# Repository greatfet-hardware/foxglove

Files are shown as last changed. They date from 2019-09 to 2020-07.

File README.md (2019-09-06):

# Foxglove
an advanced level shifting GreatFET neighbor

Required KiCad dependency:

https://github.com/greatscottgadgets/gsg-kicad-lib

If you are using git, the preferred way to install gsg-kicad-lib is to use the
submodule:

```
git submodule init && git submodule update
```

## Level Shifting

Foxglove is useful for interfacing with external targets at variety of I/O
voltage levels using a wide variety of protocols including SPI, I2C, UART, and
JTAG.  Level shifting on bank A is performed by the NXP 74LVCH1T45GW,125
supporting external voltages from 1.2 V to 5 V.  Level shifting on bank B pins
is performed by the Lattice LFE5U-12F-6BG256C (ECP5) FPGA supporting external
voltages from 1.2 V to 3.3 V.  Bank B also supports differential signals such
as LVDS.

## Pin Multiplexing

The FPGA allows Foxglove to switch arbitrary external wires to a variety of
pins on the Azalea's microcontroller in order to support a wide range of
microcontroller peripherals.

## Measurement and Probing

Foxglove provides the ability to connect an ADC, DAC, comparator, pull-up
resistor, or pull-down resistor to any of the pins on bank A.  This allows
analog measurement and probing of external targets.

Additionally, Foxglove is very useful for digital logic analysis and pattern
generation.

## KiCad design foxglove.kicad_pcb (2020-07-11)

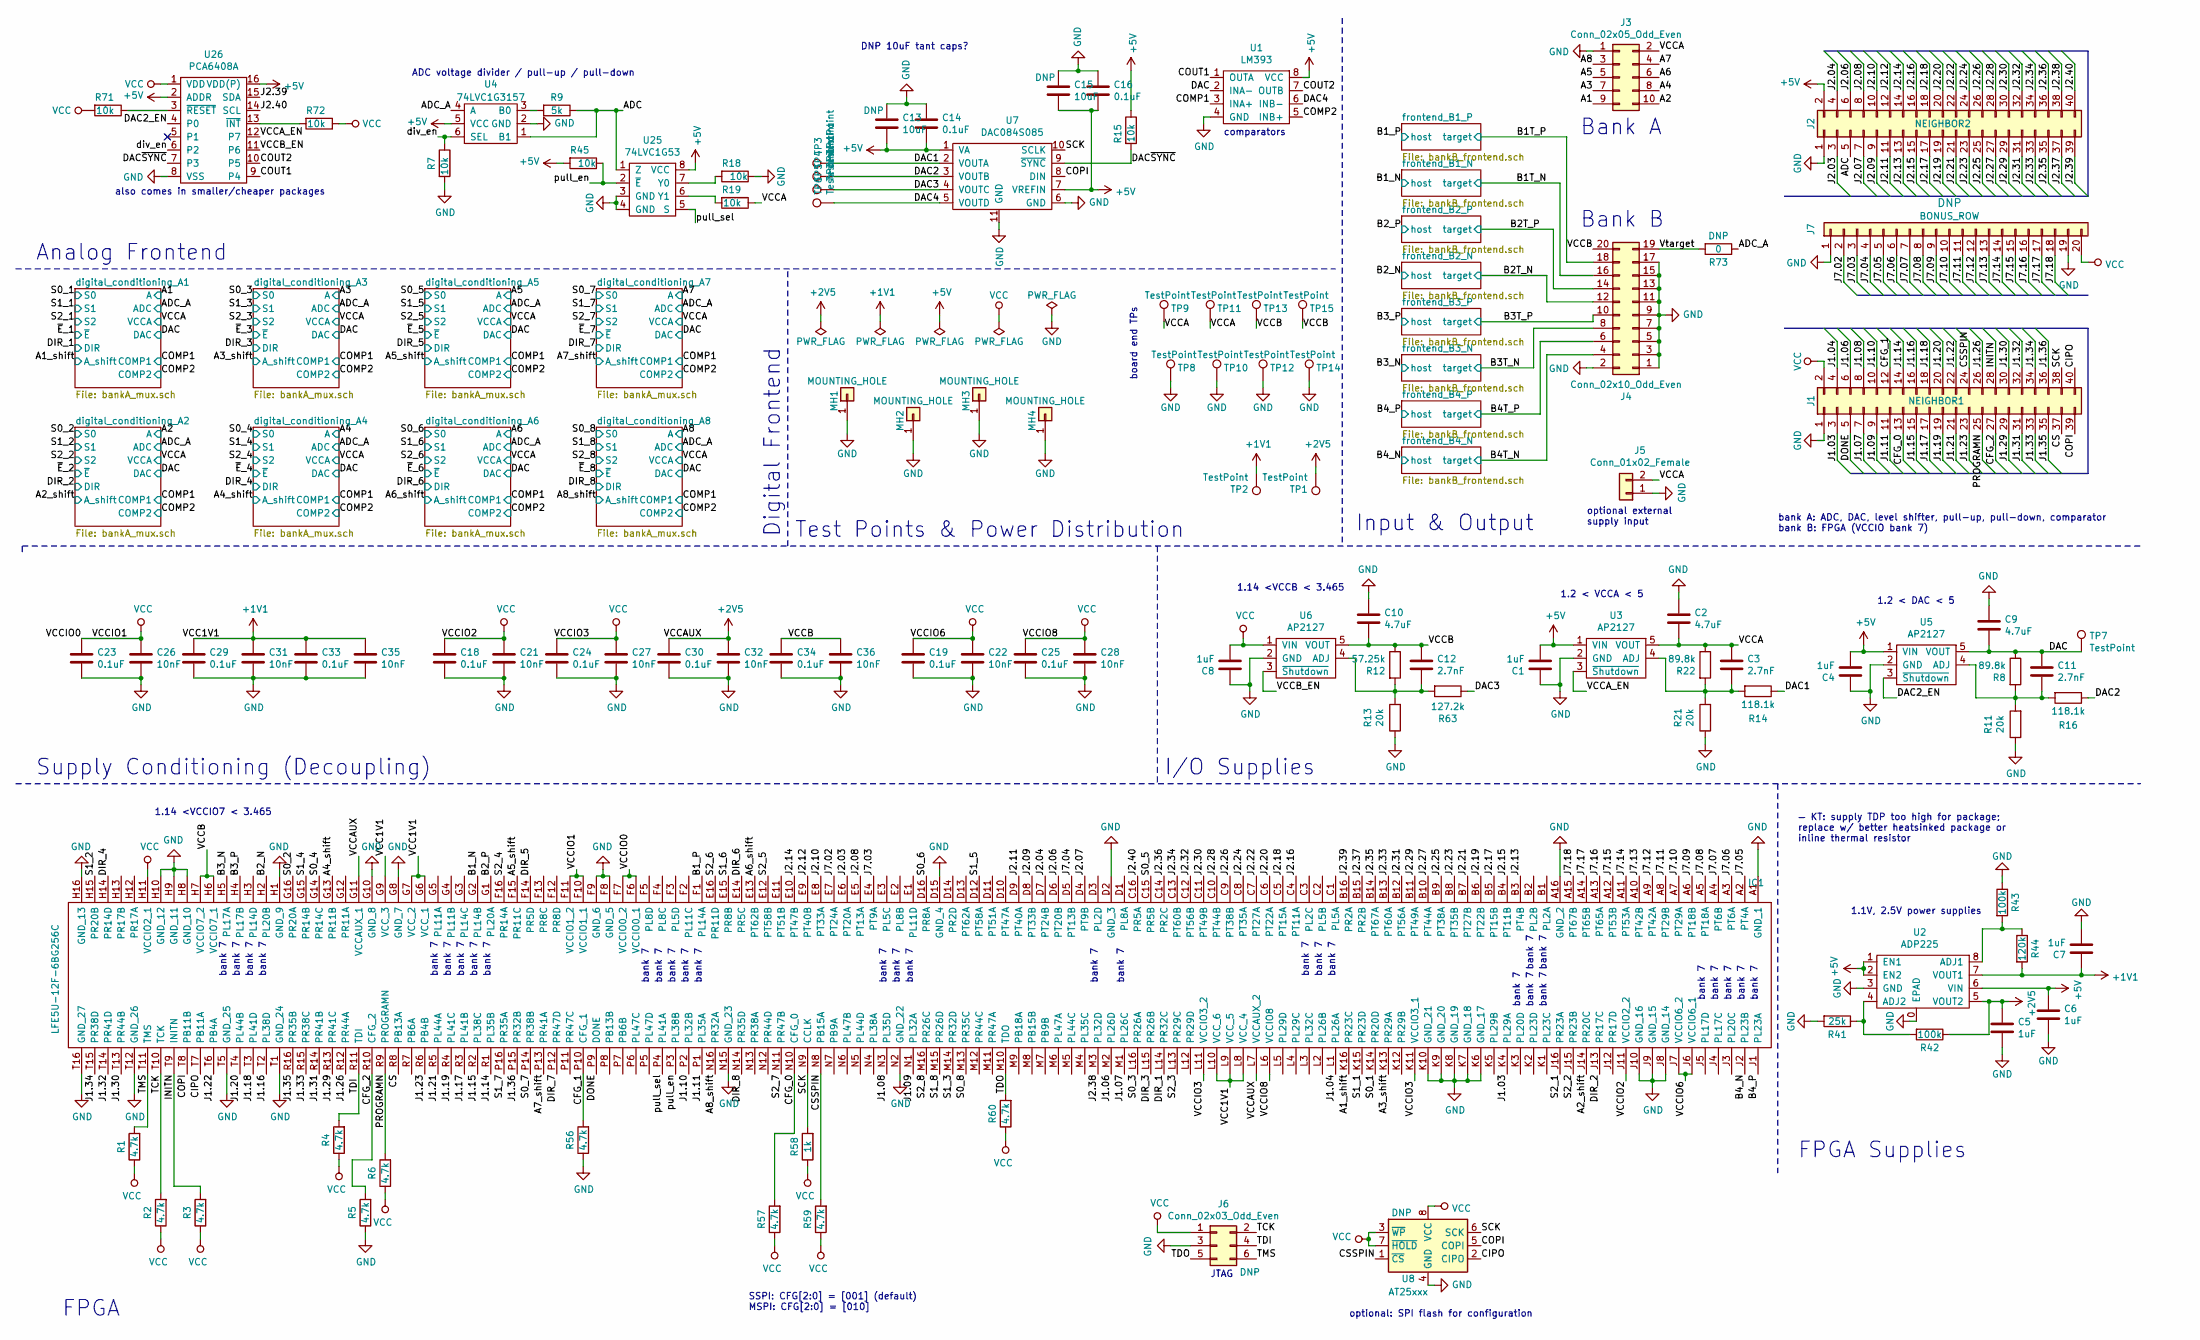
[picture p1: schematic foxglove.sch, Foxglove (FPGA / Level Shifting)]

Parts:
C1, C4, C5, C6, C7, C8: 1uF; 0402; Part Number GRT155R61E105KE01D
C2, C9, C10: 4.7uF; 0402; Part Number GRM155R61A475MEAAD
C3, C11, C12: 2.7nF; 0402; Part Number CC0402KRX7R9BB272
C13, C15: 10uF; 0603; Part Number F981A106MMA
C14, C16, C18, C19, C23, C24, C25, C29, C30, C33, C34: 0.1uF; 0402; Part Number EMK105BJ104KV-F
C21, C22, C26, C27, C28, C31, C32, C35, C36: 10nF; 0402; Part Number CL05B103KO5NNNC
IC1: LFE5U-12F-6BG256C; BGA256C80P16X16_1400X1400X170; Part Number LFE5U-12F-6BG256C; Mouser Part Number 842-LFE5U12F6BG256C
J1: NEIGHBOR1; HEADER-2x20; Part Number SSQ-120-23-G-D
J2: NEIGHBOR2; HEADER-2x20; Part Number SSQ-120-23-G-D
J3: Conn_02x05_Odd_Even; PinHeader_2x05_P2.54mm_Vertical; Part Number SBH11-PBPC-D05-RA-BK
J4: Conn_02x10_Odd_Even; PinHeader_2x10_P2.54mm_Vertical; Part Number SBH11-PBPC-D10-RA-BK
J5: Conn_01x02_Female; HEADER-1x2
J6: Conn_02x03_Odd_Even; PinHeader_2x03_P1.00mm_Vertical_SMD
J7: BONUS_ROW; HEADER-1x20; Part Number SSQ-120-23-G-S
MH1, MH2, MH3, MH4: MOUNTING_HOLE; HOLE126MIL-COPPER
R1, R2, R3, R4, R5, R6, R56, R57, R59, R60: 4.7k; 0402; Part Number RMCF0402JT4K70
R7, R15, R18, R19, R45, R71, R72: 10k; 0402; Part Number RMCF0402JT10K0
R8, R22: 89.8k; 0402; Part Number RMCF0402FT88K7
R9: 5k; 0402; Part Number PNM0402E5001BST1
R11, R13, R21: 20k; 0402; Part Number RMCF0402JT20K0
R12: 57.25k; 0402; Part Number RMCF0402FT57K6
R14, R16: 118.1k; 0402; Part Number RMCF0402FT118K
R41: 25k; 0402; Part Number PNM0402E2502BST1
R42, R43: 100k; 0402; Part Number RMCF0402JT100K
R44: 120k; 0402; Part Number RMCF0402FT120K
R58: 1k; 0402; Part Number RK73B1ETTP102J
R63: 127.2k; 0402; Part Number RMCF0402FT127K
R73: 0; 0402
TP1, TP2, TP3, TP4, TP5, TP6, TP7: TestPoint; TESTPOINT-50MIL
TP8, TP10, TP12, TP14: TestPoint; HEADER-1x1
TP9, TP11, TP13, TP15: TestPoint; HEADER-1x1-TESTPROBE
U1: LM393; SOIC8-154; Part Number LM393EDR2G
U2: ADP225; SON50P200X200X60-9N; Part Number ADP225ACPZ-R7
U3, U5, U6: AP2127; SOT-23-5; Part Number AP2127K-ADJTRG1
U4: 74LVC1G3157; SOT363; Part Number 74LVC1G3157DW-7
U7: DAC084S085; WSON-10-1EP_4x3mm_P0.5mm_EP2.2x2mm; Part Number DAC084S085CISDX/NOPB
U8: AT25xxx; SOIC8-154
U25: 74LVC1G53; VSSOP-8_2.3x2mm_P0.5mm; Part Number 74LVC1G53DC,125
U26: PCA6408A; TSSOP16; Part Number PCA6408APW,118

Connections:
+1V1: C7.1, C29.1, C31.1, C33.1, C35.1, IC1.G6 (VCC_1), IC1.G7 (VCC_2), IC1.G9 (VCC_3), IC1.L8 (VCC_4), IC1.L9 (VCC_5), IC1.L10 (VCC_6), R44.2, TP2.1, U2.7 (VOUT1)
+2V5: C5.1, C30.1, C32.1, IC1.G11 (VCCAUX_1), IC1.L7 (VCCAUX_2), R42.1, TP1.1, U2.5 (VOUT2)
+5V: C1.2, C4.2, C6.1, C13.1, C14.2, C15.1, C16.2, J2.2, R15.1, R45.2, U1.8 (VCC), U2.1 (EN1), U2.2 (EN2), U2.6 (VIN), U3.1 (VIN), U4.5 (VCC), U5.1 (VIN), U7.1 (VA), U7.7 (VREFIN), U25.8 (VCC), U26.2 (ADDR), U26.16 (VDD(P)); also elsewhere on the board
/A1_shift: IC1.K16 (PR23C); also elsewhere on the board
/A2: J3.10; also elsewhere on the board
/A2_shift: IC1.J14 (PR20C); also elsewhere on the board
/A3: J3.7; also elsewhere on the board
/A3_shift: IC1.K13 (PR29A); also elsewhere on the board
/A4_shift: IC1.G13 (PR11B); also elsewhere on the board
/A5: J3.5; also elsewhere on the board
/A5_shift: IC1.F15 (PR11C); also elsewhere on the board
/A6: J3.6; also elsewhere on the board
/A6_shift: IC1.E13 (PT62B); also elsewhere on the board
/A7: J3.4; also elsewhere on the board
/A7_shift: IC1.P13 (PR41A); also elsewhere on the board
/A8: J3.3; also elsewhere on the board
/A8_shift: IC1.N16 (PR32A); also elsewhere on the board
/ADC: J2.5, R9.1, U4.1 (B1), U25.1 (Z)
/ADC_A: R73.1, U4.4 (A); also elsewhere on the board
/B1T_N: J4.16; also elsewhere on the board
/B1T_P: J4.18; also elsewhere on the board
/B1_N: IC1.G2 (PL14B); also elsewhere on the board
/B1_P: IC1.F1 (PL14A); also elsewhere on the board
/B2T_N: J4.12; also elsewhere on the board
/B2T_P: J4.14; also elsewhere on the board
/B2_N: IC1.H2 (PL20B); also elsewhere on the board
/B2_P: IC1.G1 (PL20A); also elsewhere on the board
/B3T_N: J4.8; also elsewhere on the board
/B3T_P: J4.10; also elsewhere on the board
/B3_N: IC1.H5 (PL17A); also elsewhere on the board
/B3_P: IC1.H4 (PL17B); also elsewhere on the board
/B4T_N: J4.4; also elsewhere on the board
/B4T_P: J4.6; also elsewhere on the board
/B4_N: IC1.J2 (PL23B); also elsewhere on the board
/B4_P: IC1.J1 (PL23A); also elsewhere on the board
/CFG_0: IC1.N10 (CFG_0), J1.13, R57.2
/CFG_1: IC1.P10 (CFG_1), J1.12, R56.2
/CFG_2: IC1.R10 (CFG_2), J1.27, R5.2
/CIPO: IC1.T7 (PB11A), J1.40, U8.2 (CIPO)
/COMP1: U1.3 (INA+); also elsewhere on the board
/COMP2: U1.5 (INB+); also elsewhere on the board
/COPI: IC1.T8 (PB11B), J1.39, U7.8 (DIN), U8.5 (COPI)
/COUT1: U1.1 (OUTA), U26.9 (P4)
/COUT2: U1.7 (OUTB), U26.10 (P5)
/CS: IC1.R8 (PB13A), J1.37
/CSSPIN: IC1.N8 (PB15A), J1.24, R59.2, U8.1 (~CS)
/DAC: C9.2, C11.1, R8.1, TP7.1, U1.2 (INA-), U5.5 (VOUT); also elsewhere on the board
/DAC1: R14.1, TP3.1, U7.2 (VOUTA)
/DAC2: R16.1, TP4.1, U7.3 (VOUTB)
/DAC2_EN: U5.3 (~Shutdown~), U26.4 (P0)
/DAC3: R63.1, TP5.1, U7.4 (VOUTC)
/DAC4: TP6.1, U1.6 (INB-), U7.5 (VOUTD)
/DAC~SYNC~: R15.2, U7.9 (~SYNC~), U26.7 (P3)
/DIR_1: IC1.L14 (PR32C); also elsewhere on the board
/DIR_2: IC1.J13 (PR17C); also elsewhere on the board
/DIR_3: IC1.L15 (PR26B); also elsewhere on the board
/DIR_4: IC1.H14 (PR14D); also elsewhere on the board
/DIR_5: IC1.F14 (PR5D); also elsewhere on the board
/DIR_6: IC1.E14 (PR5C); also elsewhere on the board
/DIR_7: IC1.P12 (PR47D); also elsewhere on the board
/DIR_8: IC1.N14 (PR35D); also elsewhere on the board
/DONE: IC1.P9 (DONE), J1.5
/INITN: IC1.T9 (INITN), J1.28, R3.2
/J1.03: IC1.K4 (PL29A), J1.3
/J1.04: IC1.L1 (PL26A), J1.4
/J1.06: IC1.M2 (PL26D), J1.6
/J1.07: IC1.M1 (PL26C), J1.7
/J1.08: IC1.N3 (PL35D), J1.8
/J1.09: IC1.N1 (PL32A), J1.9
/J1.10: IC1.P2 (PL32B), J1.10
/J1.11: IC1.P1 (PL35A), J1.11
/J1.14: IC1.R1 (PL35B), J1.14
/J1.15: IC1.R2 (PL38C), J1.15
/J1.16: IC1.T2 (PL38D), J1.16
/J1.17: IC1.R3 (PL41B), J1.17
/J1.18: IC1.T3 (PL41D), J1.18
/J1.19: IC1.R4 (PL41C), J1.19
/J1.20: IC1.T4 (PL44B), J1.20
/J1.21: IC1.R5 (PL44A), J1.21
/J1.22: IC1.T6 (PB4A), J1.22
/J1.23: IC1.R6 (PB4B), J1.23
/J1.26: IC1.R12 (PR44A), J1.26
/J1.29: IC1.R13 (PR41C), J1.29
/J1.30: IC1.T13 (PR44B), J1.30
/J1.31: IC1.R14 (PR41B), J1.31
/J1.32: IC1.T14 (PR41D), J1.32
/J1.33: IC1.R15 (PR38C), J1.33
/J1.34: IC1.T15 (PR38D), J1.34
/J1.35: IC1.R16 (PR35B), J1.35
/J1.36: IC1.P15 (PR32B), J1.36
/J2.03: IC1.E6 (PT20A), J2.3
/J2.04: IC1.D7 (PT24B), J2.4
/J2.06: IC1.D6 (PT20B), J2.6
/J2.07: IC1.D4 (PT9B), J2.7
/J2.08: IC1.E5 (PT13A), J2.8
/J2.09: IC1.D8 (PT33B), J2.9
/J2.10: IC1.E8 (PT33A), J2.10
/J2.11: IC1.D9 (PT40A), J2.11
/J2.12: IC1.E9 (PT40B), J2.12
/J2.13: IC1.B3 (PT4B), J2.13
/J2.14: IC1.E10 (PT47B), J2.14
/J2.15: IC1.B4 (PT11B), J2.15
/J2.16: IC1.C4 (PT11A), J2.16
/J2.17: IC1.B5 (PT15B), J2.17
/J2.18: IC1.C5 (PT15A), J2.18
/J2.19: IC1.B6 (PT22B), J2.19
/J2.20: IC1.C6 (PT22A), J2.20
/J2.21: IC1.B7 (PT27B), J2.21
/J2.22: IC1.C7 (PT27A), J2.22
/J2.23: IC1.B8 (PT35B), J2.23
/J2.24: IC1.C8 (PT35A), J2.24
/J2.25: IC1.B9 (PT38A), J2.25
/J2.26: IC1.C9 (PT38B), J2.26
/J2.27: IC1.B10 (PT44A), J2.27
/J2.28: IC1.C10 (PT44B), J2.28
/J2.29: IC1.B11 (PT49A), J2.29
/J2.30: IC1.C11 (PT49B), J2.30
/J2.31: IC1.B12 (PT56A), J2.31
/J2.32: IC1.C12 (PT56B), J2.32
/J2.33: IC1.B13 (PT60A), J2.33
/J2.34: IC1.C13 (PT60B), J2.34
/J2.35: IC1.B14 (PT67A), J2.35
/J2.36: IC1.C14 (PR2C), J2.36
/J2.37: IC1.B15 (PR2B), J2.37
/J2.38: IC1.M3 (PL32D), J2.38
/J2.39: IC1.B16 (PR2A), J2.39, U26.15 (SDA)
/J2.40: IC1.C16 (PR5A), J2.40, U26.14 (SCL)
/J7.02: IC1.E7 (PT24A), J7.2
/J7.03: IC1.E4 (PT9A), J7.3
/J7.04: IC1.D5 (PT13B), J7.4
/J7.05: IC1.A2 (PT4A), J7.5
/J7.06: IC1.A3 (PT6A), J7.6
/J7.07: IC1.A4 (PT6B), J7.7
/J7.08: IC1.A5 (PT18A), J7.8
/J7.09: IC1.A6 (PT18B), J7.9
/J7.10: IC1.A7 (PT29A), J7.10
/J7.11: IC1.A8 (PT29B), J7.11
/J7.12: IC1.A9 (PT42A), J7.12
/J7.13: IC1.A10 (PT42B), J7.13
/J7.14: IC1.A11 (PT53A), J7.14
/J7.15: IC1.A12 (PT53B), J7.15
/J7.16: IC1.A13 (PT65A), J7.16
/J7.17: IC1.A14 (PT65B), J7.17
/J7.18: IC1.A15 (PT67B), J7.18
/PROGRAMN: IC1.R9 (PROGRAMN), J1.25, R6.2
/S0_1: IC1.K14 (PR20D); also elsewhere on the board
/S0_2: IC1.G16 (PR20A); also elsewhere on the board
/S0_3: IC1.L16 (PR26A); also elsewhere on the board
/S0_4: IC1.G14 (PR14C); also elsewhere on the board
/S0_5: IC1.C15 (PR5B); also elsewhere on the board
/S0_6: IC1.D16 (PR8A); also elsewhere on the board
/S0_7: IC1.P14 (PR38B); also elsewhere on the board
/S0_8: IC1.M13 (PR35C); also elsewhere on the board
/S1_1: IC1.K15 (PR23D); also elsewhere on the board
/S1_2: IC1.H15 (PR20B); also elsewhere on the board
/S1_3: IC1.M14 (PR32D); also elsewhere on the board
/S1_4: IC1.G15 (PR14B); also elsewhere on the board
/S1_5: IC1.D12 (PT58A); also elsewhere on the board
/S1_6: IC1.E15 (PR8B); also elsewhere on the board
/S1_7: IC1.P16 (PR35A); also elsewhere on the board
/S1_8: IC1.M15 (PR26D); also elsewhere on the board
/S2_1: IC1.J16 (PR23A); also elsewhere on the board
/S2_2: IC1.J15 (PR23B); also elsewhere on the board
/S2_3: IC1.L13 (PR29C); also elsewhere on the board
/S2_4: IC1.F16 (PR14A); also elsewhere on the board
/S2_5: IC1.E12 (PT58B); also elsewhere on the board
/S2_6: IC1.E16 (PR11D); also elsewhere on the board
/S2_7: IC1.N11 (PR47B); also elsewhere on the board
/S2_8: IC1.M16 (PR26C); also elsewhere on the board
/SCK: IC1.N9 (CCLK), J1.38, R58.2, U7.10 (SCLK), U8.6 (SCK)
/TCK: IC1.T10 (TCK), J6.2, R2.2
/TDI: IC1.R11 (TDI), J6.4, R4.2
/TDO: IC1.M10 (TDO), J6.5, R60.2
/TMS: IC1.T11 (TMS), J6.6, R1.2
/VCCA: C2.2, C3.1, J3.2, J5.2, R19.1, R22.1, TP9.1, TP11.1, U3.5 (VOUT); also elsewhere on the board
/VCCA_EN: U3.3 (~Shutdown~), U26.12 (P7)
/VCCB: C10.2, C12.1, C34.1, C36.1, IC1.H6 (VCCIO7_1), IC1.H7 (VCCIO7_2), J4.20, R12.1, TP13.1, TP15.1, U6.5 (VOUT)
/VCCB_EN: U6.3 (~Shutdown~), U26.11 (P6)
/Vtarget: J4.19, R73.2
/div_en: R7.1, U4.6 (SEL), U26.6 (P2)
/pull_en: IC1.P3 (PL38B), R45.1, U25.2 (~E~)
/pull_sel: IC1.P4 (PL41A), U25.5 (S)
GND: C1.1, C2.1, C4.1, C5.2, C6.2, C7.2, C8.1, C9.1, C10.1, C13.2, C14.1, C15.2, C16.1, C18.2, C19.2, C21.2, C22.2, C23.2, C24.2, C25.2, C26.2, C27.2, C28.2, C29.2, C30.2, C31.2, C32.2, C33.2, C34.2, C35.2, C36.2, IC1.A1 (GND_1), IC1.A16 (GND_2), IC1.D2 (GND_3), IC1.D15 (GND_4), IC1.F8 (GND_5), IC1.F9 (GND_6), IC1.G8 (GND_7), IC1.G10 (GND_8), IC1.H1 (GND_9), IC1.H8 (GND_10), IC1.H9 (GND_11), IC1.H10 (GND_12), IC1.H16 (GND_13), IC1.J8 (GND_14), IC1.J9 (GND_15), IC1.J10 (GND_16), IC1.K6 (GND_17), IC1.K7 (GND_18), IC1.K8 (GND_19), IC1.K9 (GND_20), IC1.K10 (GND_21), IC1.N2 (GND_22), IC1.N15 (GND_23), IC1.T1 (GND_24), IC1.T5 (GND_25), IC1.T12 (GND_26), IC1.T16 (GND_27), J1.1, J2.1, J3.1, J4.1, J4.2, J4.3, J4.5, J4.7, J4.9, J4.11, J4.13, J4.15, J4.17, J5.1, J6.3, J7.1, J7.19, MH1.1, MH2.1, MH3.1, MH4.1, R5.1, R7.2, R11.1, R13.1, R18.1, R21.1, R41.2, R43.1, R56.1, TP8.1, TP10.1, TP12.1, TP14.1, U1.4 (GND), U2.0 (EPAD), U2.3 (GND), U3.2 (GND), U4.2 (GND), U5.2 (GND), U6.2 (GND), U7.6 (GND), U7.11 (GND), U8.4 (GND), U25.3 (GND), U25.4 (GND), U26.8 (VSS); also elsewhere on the board
unnamed: C3.2, R14.2, R21.2, R22.2, U3.4 (ADJ)
unnamed: C11.2, R8.2, R11.2, R16.2, U5.4 (ADJ)
unnamed: C12.2, R12.2, R13.2, R63.2, U6.4 (ADJ)
unnamed: R9.2, U4.3 (B0)
unnamed: R18.2, U25.7 (Y0)
unnamed: R19.2, U25.6 (Y1)
unnamed: R41.1, R42.2, U2.4 (ADJ2)
unnamed: R43.2, R44.1, U2.8 (ADJ1)
unnamed: R71.1, U26.3 (~RESET~)
unnamed: R72.2, U26.13 (~INT~)
VCC: C8.2, C18.1, C19.1, C21.1, C22.1, C23.1, C24.1, C25.1, C26.1, C27.1, C28.1, IC1.F6 (VCCIO0_1), IC1.F7 (VCCIO0_2), IC1.F10 (VCCIO1_1), IC1.F11 (VCCIO1_2), IC1.H11 (VCCIO2_1), IC1.J6 (VCCIO6_1), IC1.J7 (VCCIO6_2), IC1.J11 (VCCIO2_2), IC1.K11 (VCCIO3_1), IC1.L6 (VCCIO8), IC1.L11 (VCCIO3_2), J1.2, J6.1, J7.20, R1.1, R2.1, R3.1, R4.1, R6.1, R57.1, R58.1, R59.1, R60.1, R71.2, R72.1, U6.1 (VIN), U8.3 (~WP), U8.7 (~HOLD), U8.8 (VCC), U26.1 (VDD); also elsewhere on the board

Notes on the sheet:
bank A: ADC, DAC, level shifter, pull-up, pull-down, comparator bank B: FPGA (VCCIO bank 7)
comparators
optional external supply input
JTAG
SSPI: CFG[2:0] = [001] (default) MSPI: CFG[2:0] = [010]
bank 7
1.14 <VCCIO7 < 3.465
1.2 < VCCA < 5
1.2 < DAC < 5
1.14 <VCCB < 3.465
ADC voltage divider / pull-up / pull-down
1.1V, 2.5V power supplies
optional: SPI flash for configuration
also comes in smaller/cheaper packages
DNP 10uF tant caps?
Analog Frontend
Test Points & Power Distribution
Supply Conditioning (Decoupling)
I/O Supplies
Input & Output
Digital Frontend
FPGA
FPGA Supplies
— KT: supply TDP too high for package; replace w/ better heatsinked package or inline thermal resistor
board end TPs
Bank B
Bank A

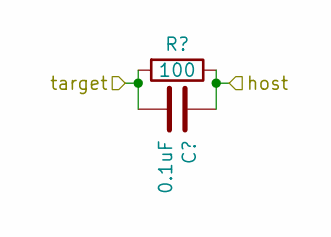
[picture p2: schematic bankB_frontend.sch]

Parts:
C17: 0.1uF; 0402; Part Number EMK105BJ104KV-F
R10: 100; 0402; Part Number RMCF0402JT100R

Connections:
/B1T_P: C17.2, R10.2; also elsewhere on the board
/B1_P: C17.1, R10.1; also elsewhere on the board

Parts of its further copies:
C44, C45, C46, C47, C48, C49, C50: 0.1uF; 0402; Part Number EMK105BJ104KV-F
R64, R65, R66, R67, R68, R69, R70: 100; 0402; Part Number RMCF0402JT100R

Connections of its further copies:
/B1T_N: C44.2, R64.2; also elsewhere on the board
/B1_N: C44.1, R64.1; also elsewhere on the board
/B2T_N: C46.2, R66.2; also elsewhere on the board
/B2T_P: C45.2, R65.2; also elsewhere on the board
/B2_N: C46.1, R66.1; also elsewhere on the board
/B2_P: C45.1, R65.1; also elsewhere on the board
/B3T_N: C48.2, R68.2; also elsewhere on the board
/B3T_P: C47.2, R67.2; also elsewhere on the board
/B3_N: C48.1, R68.1; also elsewhere on the board
/B3_P: C47.1, R67.1; also elsewhere on the board
/B4T_N: C50.2, R70.2; also elsewhere on the board
/B4T_P: C49.2, R69.2; also elsewhere on the board
/B4_N: C50.1, R70.1; also elsewhere on the board
/B4_P: C49.1, R69.1; also elsewhere on the board

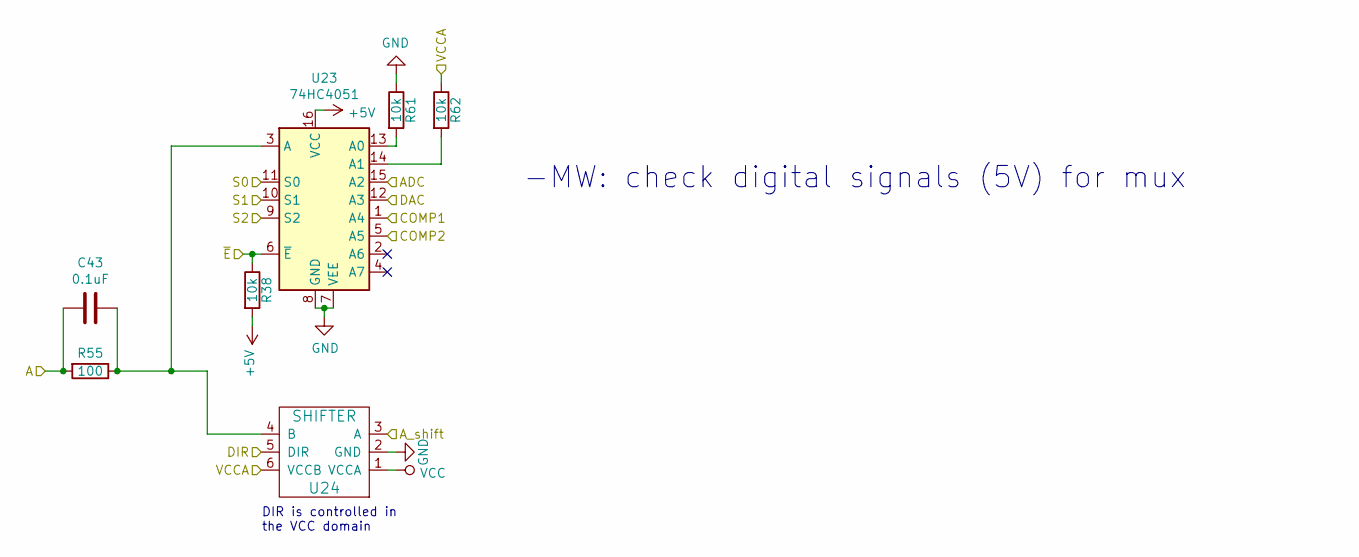
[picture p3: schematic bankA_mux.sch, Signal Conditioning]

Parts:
C39: 0.1uF; 0402; Part Number EMK105BJ104KV-F
R17, R24, R25: 10k; 0402; Part Number RMCF0402JT10K0
R48: 100; 0402; Part Number RMCF0402JT100R
U9: 74HC4051; SOT-763-1; Part Number 74HC4051BQ,115
U10: SHIFTER; SOT363; Part Number 74LVCH1T45GW,125

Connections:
+5V: R17.2, U9.16 (VCC); also elsewhere on the board
/A1_shift: U10.3 (A); also elsewhere on the board
/ADC_A: U9.15 (A2); also elsewhere on the board
/COMP1: U9.1 (A4); also elsewhere on the board
/COMP2: U9.5 (A5); also elsewhere on the board
/DAC: U9.12 (A3); also elsewhere on the board
/DIR_1: U10.5 (DIR); also elsewhere on the board
/S0_1: U9.11 (S0); also elsewhere on the board
/S1_1: U9.10 (S1); also elsewhere on the board
/S2_1: U9.9 (S2); also elsewhere on the board
/VCCA: R25.1, U10.6 (VCCB); also elsewhere on the board
/~E~_1: R17.1, U9.6 (~E)
GND: R24.1, U9.7 (VEE), U9.8 (GND), U10.2 (GND); also elsewhere on the board
unnamed: R24.2, U9.13 (A0)
unnamed: R25.2, U9.14 (A1)
VCC: U10.1 (VCCA); also elsewhere on the board

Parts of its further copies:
C20, C37, C38, C40, C41, C42, C43: 0.1uF; 0402; Part Number EMK105BJ104KV-F
R20, R23, R26, R27, R28, R29, R30, R31, R32, R33, R34, R35, R36, R37, R38, R39, R40, R46, R47, R61, R62: 10k; 0402; Part Number RMCF0402JT10K0
R49, R50, R51, R52, R53, R54, R55: 100; 0402; Part Number RMCF0402JT100R
U11, U13, U15, U17, U19, U21, U23: 74HC4051; SOT-763-1; Part Number 74HC4051BQ,115
U12, U14, U16, U18, U20, U22, U24: SHIFTER; SOT363; Part Number 74LVCH1T45GW,125

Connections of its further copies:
+5V: R20.2, R23.2, R26.2, R29.2, R32.2, R35.2, R38.2, U11.16 (VCC), U13.16 (VCC), U15.16 (VCC), U17.16 (VCC), U19.16 (VCC), U21.16 (VCC), U23.16 (VCC); also elsewhere on the board
/A2: C37.1, R49.2; also elsewhere on the board
/A2_shift: U12.3 (A); also elsewhere on the board
/A3: C38.1, R50.2; also elsewhere on the board
/A3_shift: U14.3 (A); also elsewhere on the board
/A4_shift: U16.3 (A); also elsewhere on the board
/A5: C40.1, R52.2; also elsewhere on the board
/A5_shift: U18.3 (A); also elsewhere on the board
/A6: C41.1, R53.2; also elsewhere on the board
/A6_shift: U20.3 (A); also elsewhere on the board
/A7: C42.1, R54.2; also elsewhere on the board
/A7_shift: U22.3 (A); also elsewhere on the board
/A8: C43.1, R55.2; also elsewhere on the board
/A8_shift: U24.3 (A); also elsewhere on the board
/ADC_A: U11.15 (A2), U13.15 (A2), U15.15 (A2), U17.15 (A2), U19.15 (A2), U21.15 (A2), U23.15 (A2); also elsewhere on the board
/COMP1: U11.1 (A4), U13.1 (A4), U15.1 (A4), U17.1 (A4), U19.1 (A4), U21.1 (A4), U23.1 (A4); also elsewhere on the board
/COMP2: U11.5 (A5), U13.5 (A5), U15.5 (A5), U17.5 (A5), U19.5 (A5), U21.5 (A5), U23.5 (A5); also elsewhere on the board
/DAC: U11.12 (A3), U13.12 (A3), U15.12 (A3), U17.12 (A3), U19.12 (A3), U21.12 (A3), U23.12 (A3); also elsewhere on the board
/DIR_2: U12.5 (DIR); also elsewhere on the board
/DIR_3: U14.5 (DIR); also elsewhere on the board
/DIR_4: U16.5 (DIR); also elsewhere on the board
/DIR_5: U18.5 (DIR); also elsewhere on the board
/DIR_6: U20.5 (DIR); also elsewhere on the board
/DIR_7: U22.5 (DIR); also elsewhere on the board
/DIR_8: U24.5 (DIR); also elsewhere on the board
/S0_2: U11.11 (S0); also elsewhere on the board
/S0_3: U13.11 (S0); also elsewhere on the board
/S0_4: U15.11 (S0); also elsewhere on the board
/S0_5: U17.11 (S0); also elsewhere on the board
/S0_6: U19.11 (S0); also elsewhere on the board
/S0_7: U21.11 (S0); also elsewhere on the board
/S0_8: U23.11 (S0); also elsewhere on the board
/S1_2: U11.10 (S1); also elsewhere on the board
/S1_3: U13.10 (S1); also elsewhere on the board
/S1_4: U15.10 (S1); also elsewhere on the board
/S1_5: U17.10 (S1); also elsewhere on the board
/S1_6: U19.10 (S1); also elsewhere on the board
/S1_7: U21.10 (S1); also elsewhere on the board
/S1_8: U23.10 (S1); also elsewhere on the board
/S2_2: U11.9 (S2); also elsewhere on the board
/S2_3: U13.9 (S2); also elsewhere on the board
/S2_4: U15.9 (S2); also elsewhere on the board
/S2_5: U17.9 (S2); also elsewhere on the board
/S2_6: U19.9 (S2); also elsewhere on the board
/S2_7: U21.9 (S2); also elsewhere on the board
/S2_8: U23.9 (S2); also elsewhere on the board
/VCCA: R28.1, R31.1, R34.1, R37.1, R40.1, R47.1, R62.1, U12.6 (VCCB), U14.6 (VCCB), U16.6 (VCCB), U18.6 (VCCB), U20.6 (VCCB), U22.6 (VCCB), U24.6 (VCCB); also elsewhere on the board
/~E~_2: R20.1, U11.6 (~E)
/~E~_3: R23.1, U13.6 (~E)
/~E~_4: R26.1, U15.6 (~E)
/~E~_5: R29.1, U17.6 (~E)
/~E~_6: R32.1, U19.6 (~E)
/~E~_7: R35.1, U21.6 (~E)
/~E~_8: R38.1, U23.6 (~E)
GND: R27.1, R30.1, R33.1, R36.1, R39.1, R46.1, R61.1, U11.7 (VEE), U11.8 (GND), U12.2 (GND), U13.7 (VEE), U13.8 (GND), U14.2 (GND), U15.7 (VEE), U15.8 (GND), U16.2 (GND), U17.7 (VEE), U17.8 (GND), U18.2 (GND), U19.7 (VEE), U19.8 (GND), U20.2 (GND), U21.7 (VEE), U21.8 (GND), U22.2 (GND), U23.7 (VEE), U23.8 (GND), U24.2 (GND); also elsewhere on the board
unnamed: C37.2, R49.1, U11.3 (A), U12.4 (B)
unnamed: C38.2, R50.1, U13.3 (A), U14.4 (B)
unnamed: C40.2, R52.1, U17.3 (A), U18.4 (B)
unnamed: C41.2, R53.1, U19.3 (A), U20.4 (B)
unnamed: C42.2, R54.1, U21.3 (A), U22.4 (B)
unnamed: C43.2, R55.1, U23.3 (A), U24.4 (B)
unnamed: R27.2, U11.13 (A0)
unnamed: R28.2, U11.14 (A1)
unnamed: R30.2, U13.13 (A0)
unnamed: R31.2, U13.14 (A1)
unnamed: R33.2, U15.13 (A0)
unnamed: R34.2, U15.14 (A1)
unnamed: R36.2, U17.13 (A0)
unnamed: R37.2, U17.14 (A1)
unnamed: R39.2, U19.13 (A0)
unnamed: R40.2, U19.14 (A1)
unnamed: R46.2, U21.13 (A0)
unnamed: R47.2, U21.14 (A1)
unnamed: R61.2, U23.13 (A0)
unnamed: R62.2, U23.14 (A1)
VCC: U12.1 (VCCA), U14.1 (VCCA), U16.1 (VCCA), U18.1 (VCCA), U20.1 (VCCA), U22.1 (VCCA), U24.1 (VCCA); also elsewhere on the board

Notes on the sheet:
DIR is controlled in the VCC domain
-MW: check digital signals (5V) for mux

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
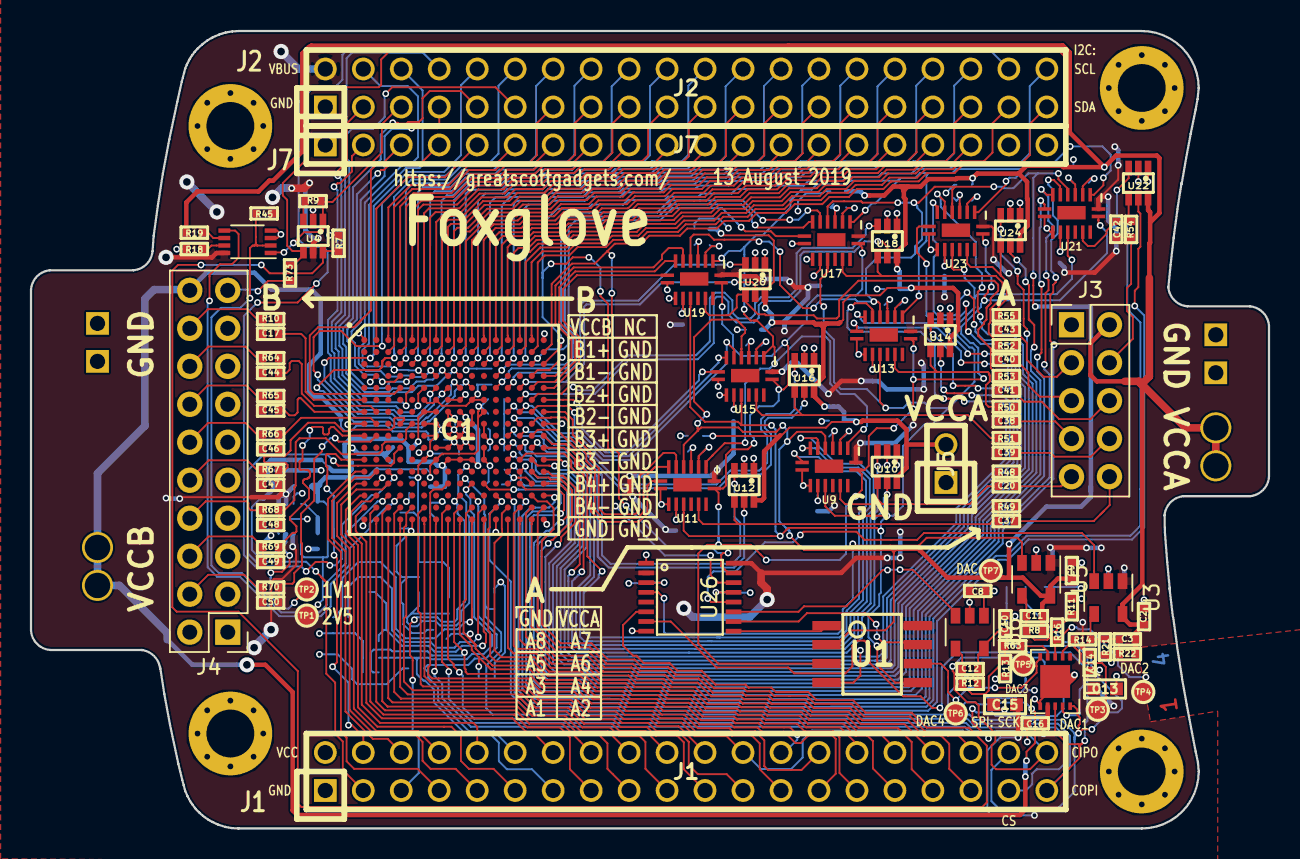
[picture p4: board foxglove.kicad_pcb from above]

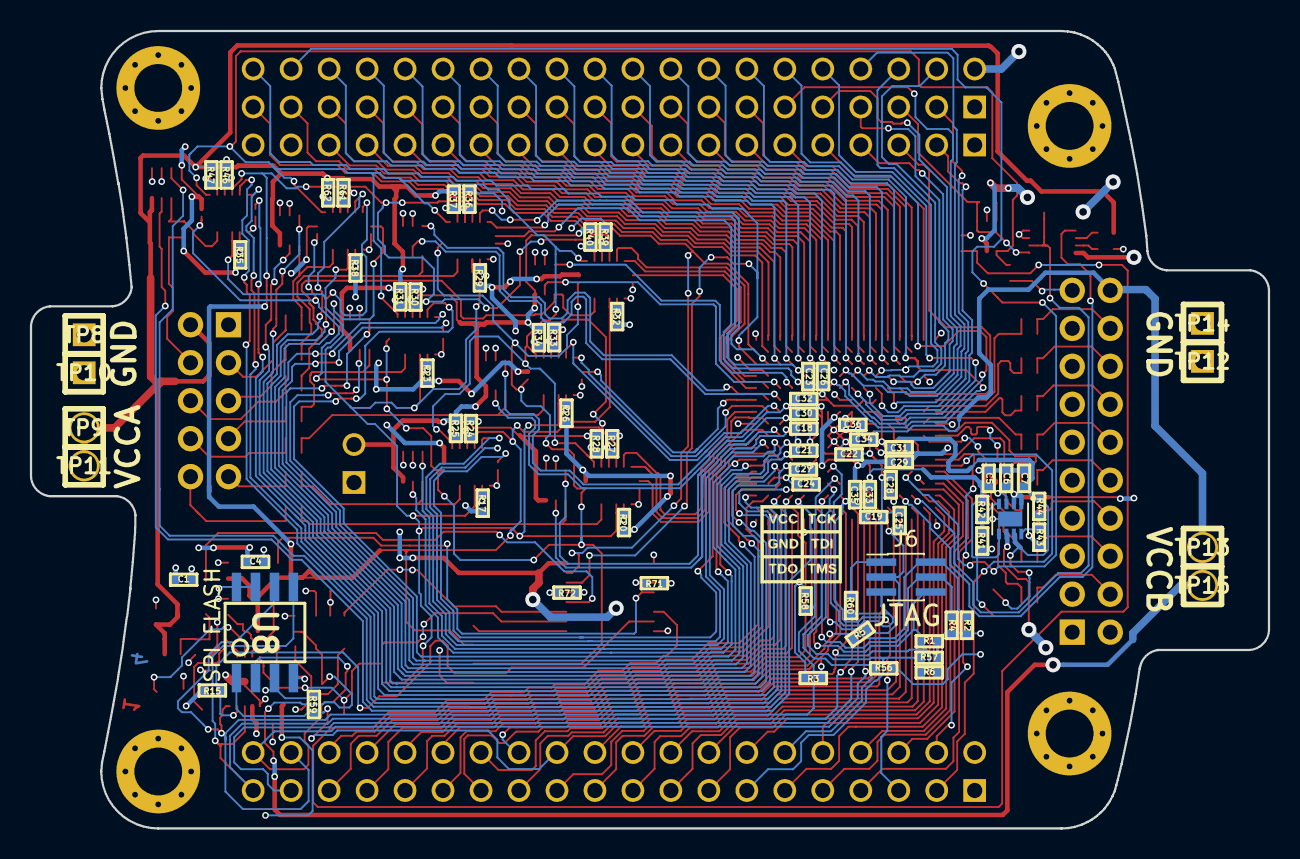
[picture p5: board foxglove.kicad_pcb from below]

Board: 4 copper layers, 82.8 x 53.3 mm, 176 parts (76 on the bottom side), 228 nets.

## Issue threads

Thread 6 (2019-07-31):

update J4 part selection

mossmann, 2019-07-31:
It should be a shrouded male right-angle pin header.

mwinchester94, 2019-08-13:
Part number correct as is (checked on digikey: https://www.digikey.com/product-detail/en/sullins-connector-solutions/SBH11-PBPC-D10-RA-BK/S9180-ND/1990073).

straithe, 2021-11-01:
@mossmann what is the status of this issue?

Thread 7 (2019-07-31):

rotate J4

mossmann, 2019-07-31:
The J4 footprint should be rotated so that the pin 1 mark agrees with the mark on the header and on ribbon cables.  The connections should be rotated in the schematic as well so that all the traces can stay where they are.

mwinchester94, 2019-08-13:
Rotated J4, issue resolved.

straithe, 2021-11-01:
@mossmann please confirm that this issue can be closed.

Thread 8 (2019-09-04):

component question

evanrichter, 2019-09-04:
(don't take this as criticisms, I'm pretty new to hardware design, and I'm really looking forward to the development of this neighbor!)

what are your plans for the fpga (what makes foxglove advanced beyond a level shifter)? what would it do beyond something simple like a couple of [these](https://www.nxp.com/part/GTL2000DGG) bi-directional translators?

mossmann, 2019-09-04:
The FPGA allows us to remap pins, so you can connect to unknown test points on a target device, probe it to discover that there is, for example, a UART on a couple of pins, and then remap those pins onto a UART peripheral on the LPC4330 (on Azalea) without having to rewire the target.  It will also permit implementation of high speed serial or parallel interfaces that would be difficult or impossible to implement on the LPC4330 alone.

In addition to the FPGA, there are a bunch of other advanced features enabled by analog multiplexers that can connect a pin to a variety of pull-ups, pull-downs, ADCs, DACs, or comparators in addition to connecting to the FPGA.  This gives us a tremendous range of options for measurement, probing, or even implementation of analog interfaces.

Bi-directional level shifters without direction pins such as the GTL2000 can be quite useful in certain fixed implementations, but they tend to misbehave if rewired to arbitrary targets.  Instead we use a separate level shifter with a direction pin on each pin of Foxglove's bank A, and we provide direct connection to the FPGA through bank B.

evanrichter, 2019-09-05:
thanks for the detailed update! I think I will up my kicad game and implement a GTL2000 based neighbor with header pins on each end of the IC, for manual rewiring to the greatfet depending on the user's need for spi, uart, sgpio, etc. Shouldn't be _too complicated_ :)

> Bi-directional level shifters without direction pins ... tend to misbehave if rewired to arbitrary targets.

What does this mean exactly? Are you talking about a target that operates at multiple logic levels? I agree the GTL2000 would not support that

mossmann, 2019-09-06:
The level shifters on Foxglove (74LVCH1T45GW,125) have a pin that controls direction. We can drive that pin high or low depending on which side of the shifter we want to be the input and which side we want to be the output.  We use a separate level shifter for each external pin, so we can change their directions independent of each another.

The GTL2000 does not give you any way to control which side is the input and which is the output.  It has some method of determining which way to translate dynamically.  I skimmed the data sheet but still don't understand this very well.

Depending on the application, the GTL2000 requires pull-up resistors on one or both sides.  It can drive any pin low, but in some cases it can't drive pins high.  This makes it incompatible with signals that have pull-down resistors.  We had the very same [issue](https://github.com/greatfet-hardware/jasmine/issues/7) with an I/O expander on Jasmine recently and had to find a new part capable of driving its outputs high or low.

Closed 2019-09-23.

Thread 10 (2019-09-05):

U2 overheats

mossmann, 2019-09-05:
LDO packages is very small and lacks required heat dissipation.

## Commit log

2019-03-27 Added iCE40-HX8K-CT256 to schematic, began signal routing.
    [foxglove.kicad_pcb, foxglove.sch, power_supplies.sch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]
2019-03-29 Foxglove: Routed signals to FPGA and set up bank A multiplexors
    [bankA_mux.sch, foxglove.kicad_pcb, foxglove.sch]
2019-03-29 Continued work on Foxglove schematic (added bypass caps, selected footprints, etc.). Placed parts on PCB.
    [bankA_mux.sch, foxglove.kicad_pcb, foxglove.sch]
2019-04-04 Routed FPGA connections to J2 connector
    [bankA_mux.sch, foxglove.kicad_pcb, foxglove.sch]
2019-04-05 Foxglove: Routed FPGA to J1 header
    [foxglove.kicad_pcb, foxglove.sch]
2019-04-09 Added design notes
    [bankA_mux.sch, foxglove.sch]
2019-04-16 Added switch for pull-up/down in parallel with ADC
    [bankA_mux.sch, foxglove.sch]
2019-04-19 Added LFE5U-12F-6BG256C to schematic
    [foxglove.sch]
2019-04-24 Routed FPGA power and JTAG connections
    [bankA_mux.sch, foxglove.kicad_pcb, foxglove.sch]
2019-05-01 Made FPGA connections to greatfet headers
    [bankA_mux.sch, foxglove.sch]
2019-05-02 Started routing connections to J2 and J7
    [bankA_mux.sch, foxglove.kicad_pcb, foxglove.sch]
2019-05-03 Routed all greatfet headers to FPGA
    [foxglove.kicad_pcb, foxglove.sch]
2019-05-07 Changed DAC controlled LDO
    [bankA_mux.sch, foxglove.sch]
2019-05-13 Connected bank B to VCCIO7 pins, switched out voltage regulators
    [bankA_mux.sch, foxglove.kicad_pcb, foxglove.sch]
2019-05-14 Added DAC2 LDO
    [foxglove.sch]
2019-05-14 Added LDOs for DAC and VCCB
    [bankA_mux.sch, foxglove.sch]
2019-05-22 Routed bank B to FPGA VCCIO7, added bypass caps
    [foxglove.kicad_pcb, foxglove.sch]
2019-05-22 Routed ADC/DAC and FPGA passives
    [foxglove.kicad_pcb, foxglove.sch]
2019-05-23 Corrected DAC caps, added DAC test points
    [foxglove.kicad_pcb, foxglove.sch]
2019-05-27 split foxglove into separate repository
    [azalea.kicad_pcb, azalea.sch, begonia.kicad_pcb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]
2019-05-28 Began routing bank A
    [foxglove.kicad_pcb]
2019-06-04 removed old sub-level schematics 'shifters' and 'power_supplies' and added new schematic 'bankA_mux'
    [bankA_mux.sch, power_supplies.sch, shifters.sch]
2019-06-04 Fixed sym-lib-table and continued routing bank A
    [foxglove.kicad_pcb]
2019-06-19 Changed headers for bank A and B, combined ADC voltage divider / pull-ups
    [bankA_mux.sch, bankB_frontend.sch, foxglove.kicad_pcb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]
2019-06-20 Completed routing of new connectors.
    [bankA_mux.sch, bankB_frontend.sch, foxglove.kicad_pcb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]
2019-06-21 Completed Bank A mux routing.
    [bankA_mux.sch, foxglove.kicad_pcb, foxglove.sch]
2019-06-25 Added I2C IO expander
    [bankA_mux.sch, foxglove.kicad_pcb, foxglove.sch]
2019-06-26 Completed routing
    [bankA_mux.sch, foxglove.kicad_pcb, foxglove.sch]
2019-07-02 Matched path length of bank B differential pairs
    [bankA_mux.sch, foxglove.kicad_pcb, foxglove.sch]
2019-07-02 Changed bank A footprint and rearranged silkscreen
    [bankA_mux.sch, foxglove.kicad_pcb, foxglove.sch]
2019-07-08 Added silkscreen tables for banks and completed BOM data
    [bankA_mux.sch, bankB_frontend.sch, foxglove.kicad_pcb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]
2019-07-23 Corrected FPGA footprint
    [foxglove.kicad_pcb]
2019-07-30 Improved silkscreen table visibility and changed board edge cuts to support right-angle connectors
    [bankA_mux.sch, foxglove.kicad_pcb, foxglove.sch]
2019-08-14 Flipped J4 footprint
    [foxglove.kicad_pcb, foxglove.sch]
2019-09-04 schematic: cleanup and squish onto a page
    [bankA_mux.sch, bankB_frontend.sch, foxglove.sch]
2019-09-06 update .gitignore for KiCad 5.1
2020-07-03 adopt OSHWA convention for SPI signal names https://www.oshwa.org/a-resolution-to-redefine-spi-signal-names
    [foxglove.kicad_pcb, foxglove.sch]

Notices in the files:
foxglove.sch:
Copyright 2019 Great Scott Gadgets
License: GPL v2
